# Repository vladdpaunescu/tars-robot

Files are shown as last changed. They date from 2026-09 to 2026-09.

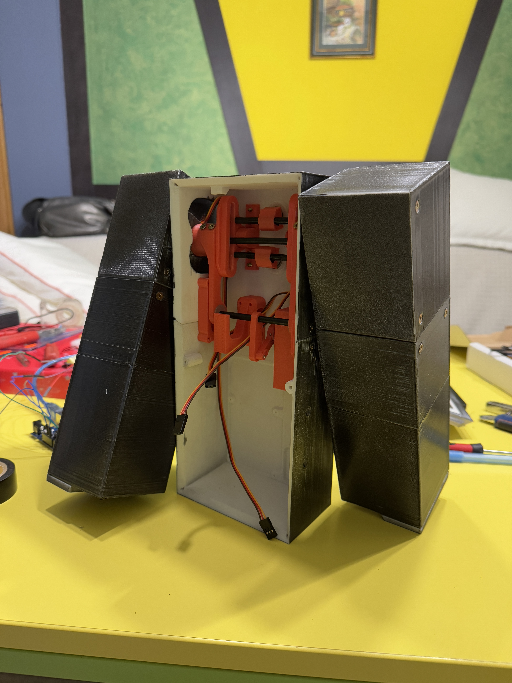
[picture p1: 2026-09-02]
docs/photos/IMG_1189.JPG

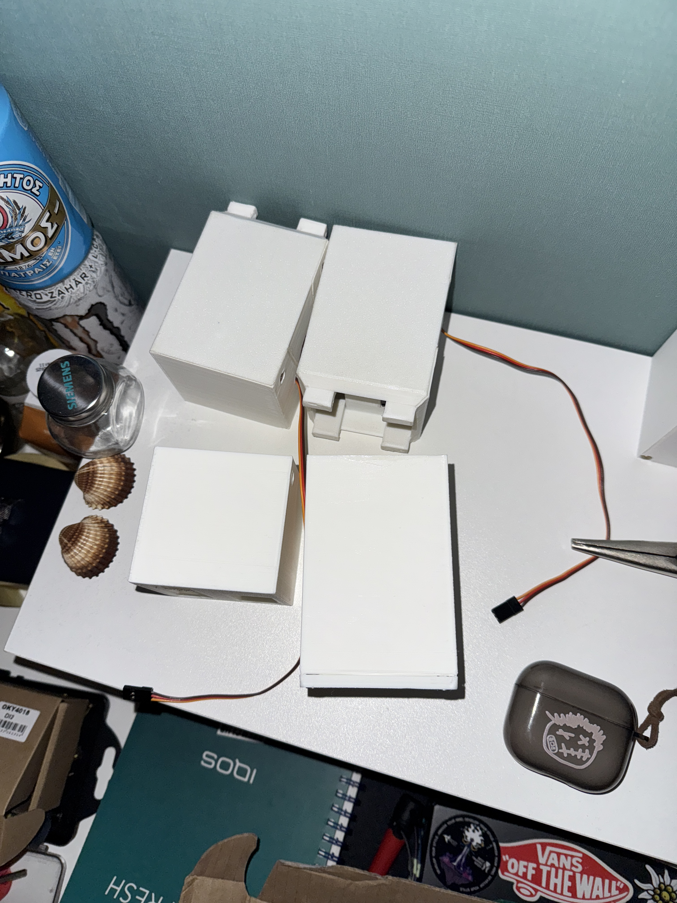
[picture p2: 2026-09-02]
docs/photos/IMG_1141.JPG

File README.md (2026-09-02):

# TARS Robot

As part of the Robotics course, I developed a robot inspired by the character TARS from the movie *Interstellar*. This project was a challenge, requiring the integration of knowledge in mechanics, electronics, and computer science.

## Overview

TARS is a walking robot that replicates the rectangular monolith locomotion of its cinematic counterpart. It pivots and steps forward by coordinating three servo motors through a Raspberry Pi, controlled in real time via an Xbox gamepad.

## Hardware

| Component | Role |
| --- | ---- |
| Raspberry Pi | Main compute unit, runs all Python code |
| PCA9685 PWM driver | Controls up to 16 servos over I2C (address `0x40`) |
| Servo — Center Lift (ch 0) | Raises and lowers the torso vertically |
| Servo — Port Drive (ch 1) | Rotates the torso to the port (left) side |
| Servo — Starboard Drive (ch 2) | Rotates the torso to the starboard (right) side |
| Xbox controller | Wireless gamepad input via `evdev` |

## Mechanics

All structural parts were designed in Fusion 360 (`cad/tars_redefined_2 v5.f3d`) and 3D-printed.

### Body

- Upper and lower chassis, upper/lower lids
- Suspension assembly: main leg mounts, suspension mounts (left/right), spring drivers, upper structure mounts, servo wheel mounts, vertical servo clips, screen support
- Axle assembly: main axle and secondary axles

### Feet

- Arms, hulls, foot pads, lids, servo clips

## Software Architecture

```text
TARS_Runner.py            ← entry point; reads Xbox controller events
    └── TARS_Servo_Abstractor3.py  ← high-level motion commands
            └── TARS_Servo_Controller3.py  ← low-level PWM sequences
```

### TARS_Runner.py

Reads gamepad events via `evdev` and dispatches motion commands:

| Input | Action |
| ----- | --- |
| D-Pad Up | Step forward |
| D-Pad Left | Turn left |
| D-Pad Right | Turn right |
| D-Pad Down | Toggle pose / unpose |
| Button X + mode | Star main motion (plus/minus direction) |
| Button `+` / `-` | Toggle direction mode |

### TARS_Servo_Abstractor3.py

High-level gait primitives built from controller sequences:

- `stepForward()` — lift → lean forward → bump → return
- `turnLeft()` / `turnRight()` — lower → pivot → return to neutral
- `pose()` / `unpose()` — lean backward into display pose and recover

### TARS_Servo_Controller3.py

Low-level servo control using `Adafruit_PCA9685`. Manages smooth PWM transitions with configurable speed (sleep intervals between increments) and supports parallel axis movement via Python threads.

### pozitie_initiala_servo.io.ino

Arduino sketch used during calibration to set all servos to their neutral positions via the PCA9685 library.

## Repository Structure

```text
tars-robot/
├── TARS_Runner.py                  # Main controller loop
├── TARS_Servo_Abstractor3.py       # High-level motion abstraction
├── TARS_Servo_Controller3.py       # Low-level PWM servo control
├── pozitie_initiala_servo.io/      # Arduino calibration sketch
├── cad/                            # Fusion 360 source + STL files
│   ├── tars_redefined_2 v5.f3d
│   ├── BODY/
│   └── FOOTS/
└── docs/                           # Documentation, schematics, and photos
    ├── Documentation.pdf
    ├── Proiect_Robo_Paunescu_Plesu.docx
    ├── RobotTars-Copiere.pptx
    ├── 525125-Schematic__50863__42807.webp
    └── photos/
```

## Dependencies

```text
evdev
Adafruit_PCA9685
smbus
```

Install on Raspberry Pi:

```bash
pip install evdev adafruit-pca9685 smbus2
```

## Running

```bash
python3 TARS_Runner.py
```

Ensure the PCA9685 is connected on I2C bus 1 and the Xbox controller is detected at `/dev/input/event8` (adjust the path in `TARS_Runner.py` if needed).

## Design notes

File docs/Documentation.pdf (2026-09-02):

### Departamentul Automatică şi Tehnologia Informaţiei

# PROIECT LA ROBOTICĂ

# Robot TARS

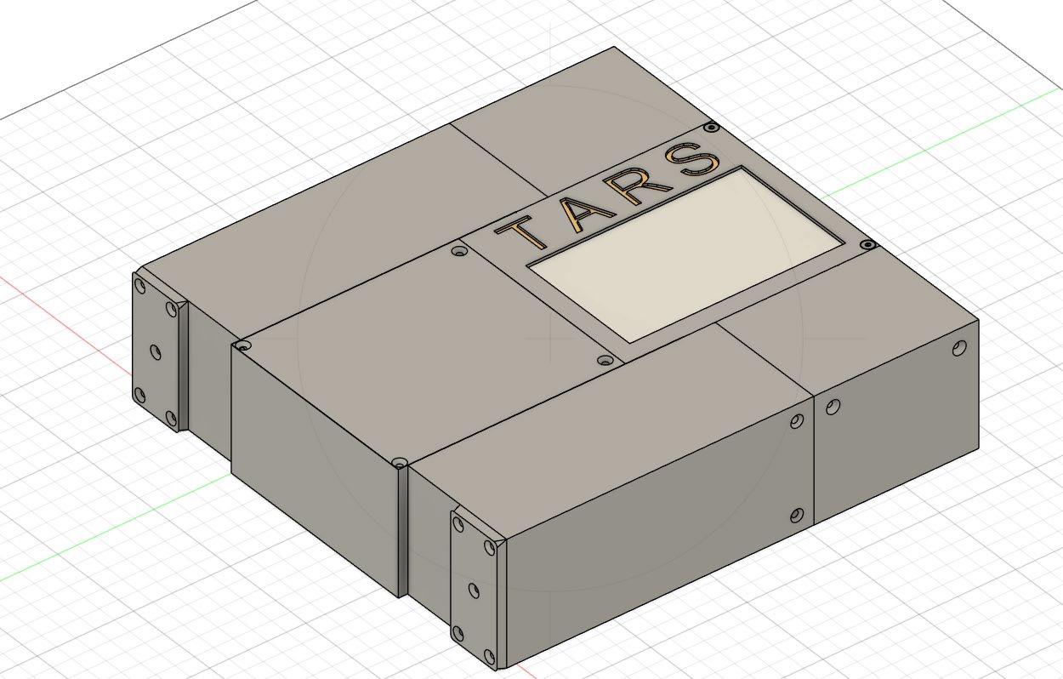
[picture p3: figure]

## Păunescu Vlad-Ioan Pleșu Robert Ștefănuț

## Gr.4LF433 - AIA - II

### BRAȘOV, 2024-2025

Departamentul Automatică şi Tehnologia Informaţiei
Programul de studii Automatică şi Informatică Aplicată - Tehnologia Informației - Robotică Proiect la PA - SDA - JAVA

## CUPRINS

Proiect la PA - SDA - JAVA

### Cap 1. DESCRIEREA SCOPULUI ȘI A FUNCȚIONALITĂȚII ROBOTULUI

Robotul TARS este un asistent robotic inovator, proiectat să combine utilitatea practicului cu o prezență socială agreabilă. Conceput pentru a sprijini utilizatorii în activitățile lor zilnice, TARS aduce un echilibru perfect între funcționalitate și design simplificat.

### 1.1 Caracteristici inovatoare

Deși la prima vedere TARS poate părea un robot minimalist, cu o structură bazată pe două picioare, fiecare echipat cu o singură articulație, complexitatea sa inginerescă stă într-un mecanism avansat de mobilitate. Pentru a depăși limitările inițiale, echipa de dezvoltare a proiectat un sistem de suspensie unic, imprimat 3D, care a transformat mobilitatea robotului în mod semnificativ.

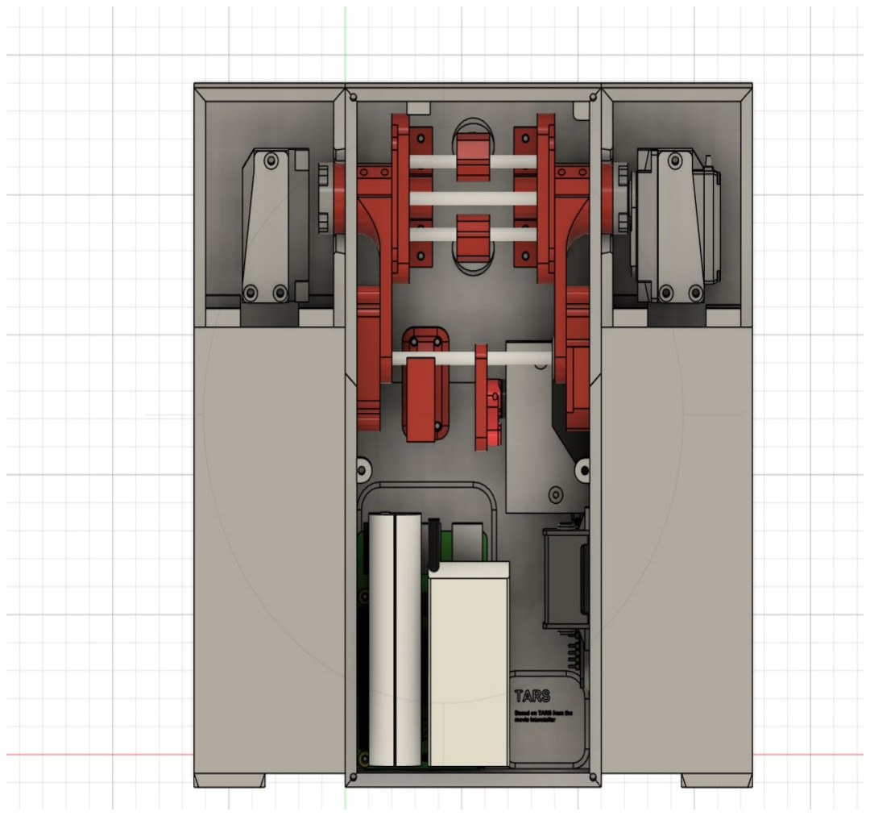
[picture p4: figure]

Figura 1 - Asamblu interior

Proiect la PA - SDA - JAVA

### 1.2 Provocări și soluții

La primele teste, robotul s-a confruntat cu restricții în mișcare, cauzate de lipsa unui mecanism de flexibilitate între picioare și trunchiul central. Soluția a constat într-un sistem de suspensie integrat, care permite transferul mișcării printr-o punte centrală ridicată, acționată de motoare de mare precizie. Această punte nu doar că permite mișcări naturale ale brațelor, dar oferă și stabilitate crescută pe durata mersului.

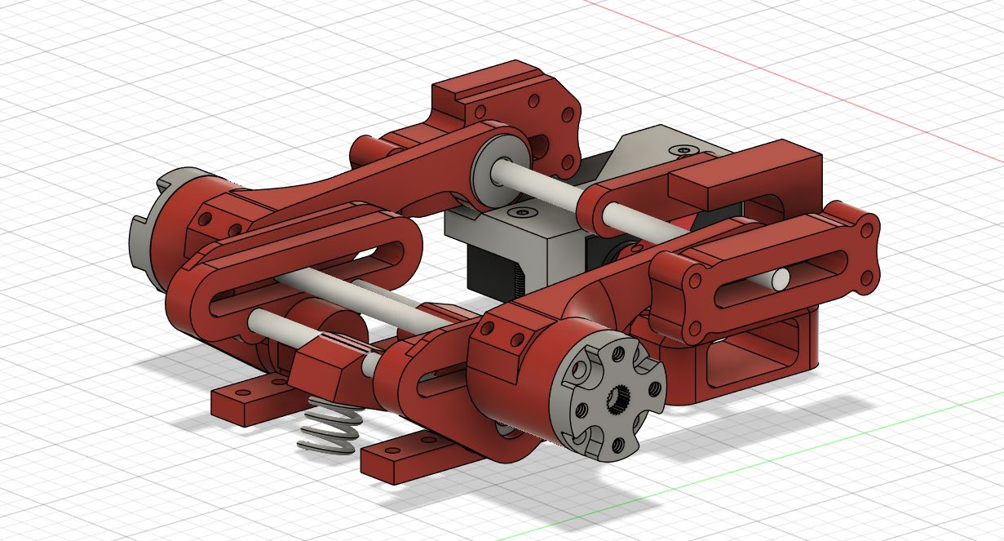
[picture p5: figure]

Figura 2 - Sistem de suspensie

Pe partea de software, au apărut dificultăți legate de afișarea pe ecran și de conceperea unui cod pentru apelarea unui sistem de inteligență artificială. Deoarece nu am găsit o soluție AI gratuită potrivită, am analizat alternative și am decis să folosim un controller de Xbox One pentru a controla mișcările robotului. Această abordare a oferit o soluție practică, facilitând controlul robotului în timp ce explorăm opțiuni AI pe termen lung.

Proiect la PA - SDA - JAVA

### 1.3 Rezultate

Datorită acestor ajustări, TARS a trecut de la un prototip funcțional, dar instabil, la un model robust și fiabil. Acum, robotul este capabil să execute mișcări continue timp de ore într-un mod natural, replicând fidel mișcările inspirate din celebra producție cinematografică.
Am reușit să conectăm ecranul robotului, afișând deocamdată doar linii de cod. Totodată, robotul răspunde prompt la comenzile transmise prin controllerul de Xbox One, asigurând o interacțiune eficientă și fluidă cu utilizatorul.

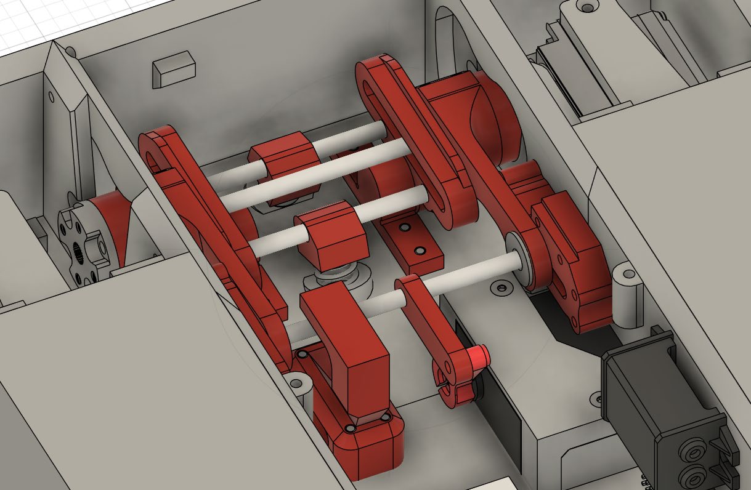
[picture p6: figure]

Figura 3 - Sistemul de suspensie in configuratia robotului

Proiect la PA - SDA - JAVA

### Cap. 2. ARHITECTURA

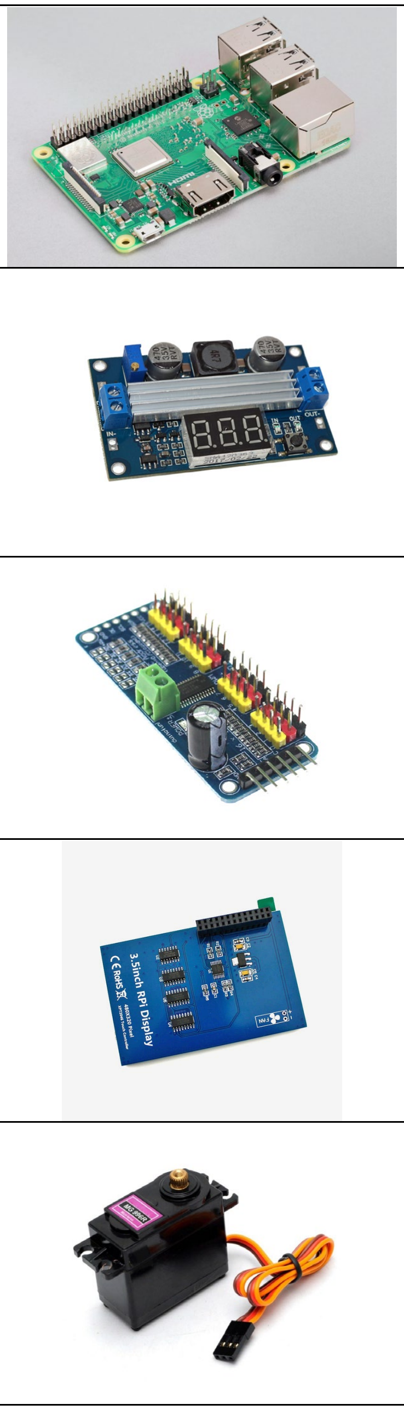
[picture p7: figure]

Raspberry Pi Model 3B+ (https://www.hackster.io/raspberry-pi/products/raspberry-pi-3-model-b?ref=project-224833)

DC Convertor de Joasa Tensiune 12V-6V

16-Channel 12-bit PWM/Servo Driver I2C interface PCA9685

3.5" RPI Display XPT2046

3x MG996R Servo motor

Proiect la PA - SDA - JAVA

### Cap. 3 CODUL FOLOSIT

### 3.1. Servo Abstractor:

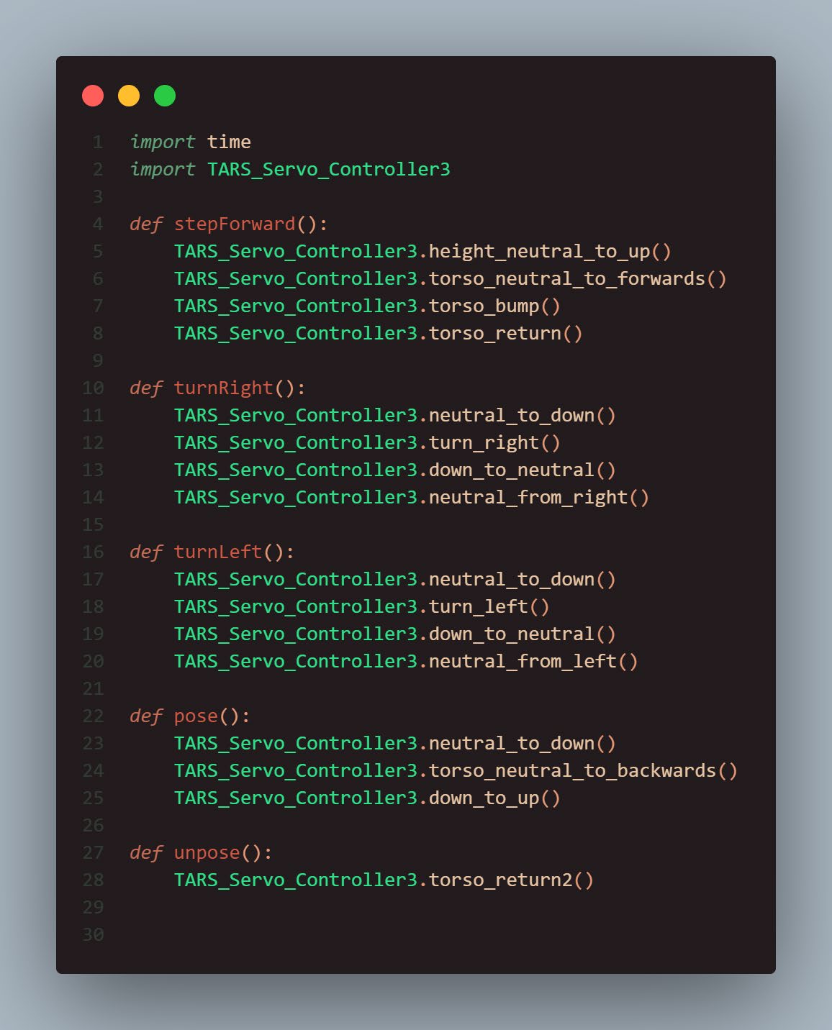
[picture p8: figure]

Proiect la PA - SDA - JAVA

### 3.2 TARS Runner

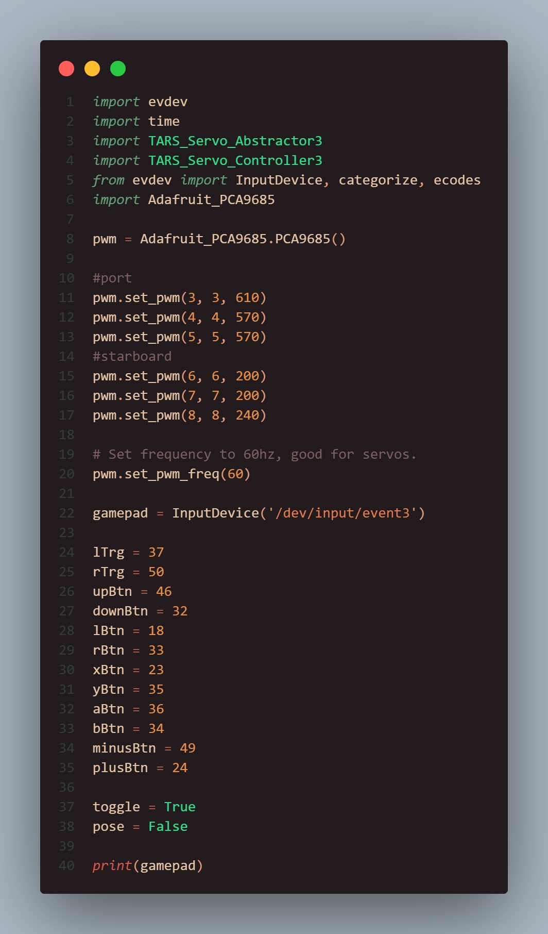
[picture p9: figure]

Proiect la PA - SDA - JAVA

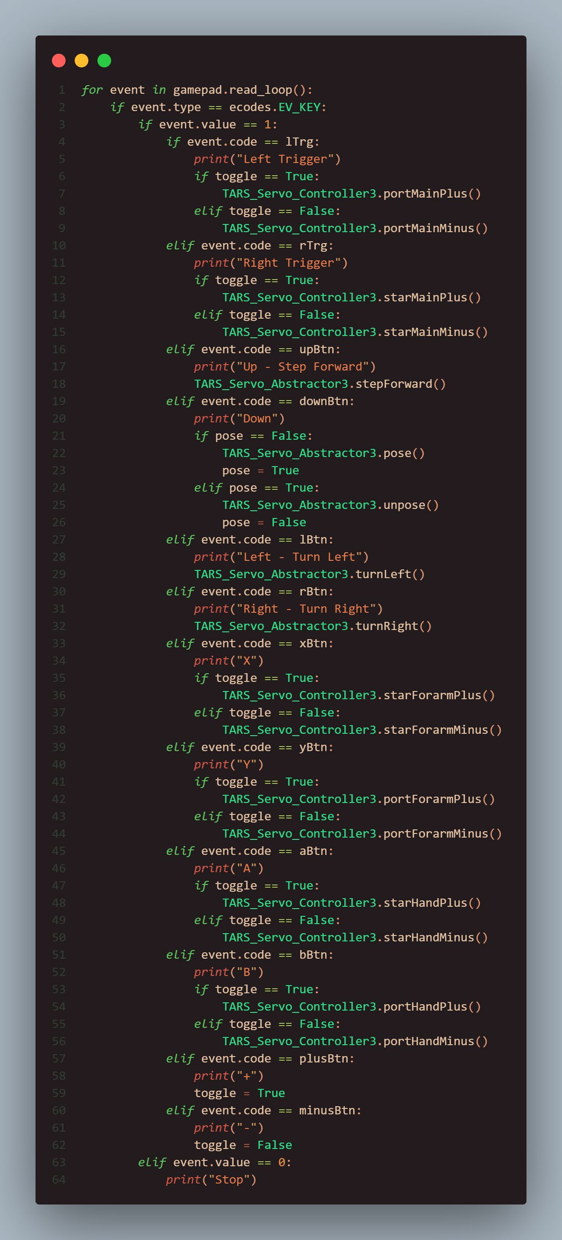
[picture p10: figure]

Proiect la PA - SDA - JAVA

### 3.3. Servo Controller

Proiect la PA - SDA - JAVA

Proiect la PA - SDA - JAVA

### Cap. 4. PLANURI DE VIITOR

Un obiectiv esențial în dezvoltarea viitoare a robotului TARS este integrarea comenzilor vocale, susținută de tehnologii avansate de inteligență artificială. Această funcționalitate va permite utilizatorilor să comunice direct cu robotul, care va interpreta și executa comenzi în timp real, devenind astfel un asistent interactiv și personalizat.
Totodată, securitatea și confidențialitatea datelor sunt priorități majore. Pentru a proteja informațiile utilizatorilor, TARS va procesa local toate interacțiunile, evitând transmiterea datelor către servere externe și respectând normele GDPR. În plus, vor fi implementate funcții pentru gestionarea și ștergerea datelor, oferind utilizatorilor control deplin asupra informațiilor personale.
Progresul proiectului va fi susținut prin colaborări strategice cu organizații de cercetare, universități și companii din domeniul roboticii și AI. Aceste parteneriate vor facilita integrarea unor tehnologii de ultimă generație și testarea robotului în diverse medii controlate, pentru a asigura performanțe optime.

### Cap. 5. VIITORUL ROBOTULUI TARS

Pe lângă integrarea comenzilor vocale și a inteligenței artificiale, TARS are un potențial vast de extindere, vizând multiple direcții de dezvoltare:
- Design modular: Robotul va fi îmbunătățit atât estetic, cât și funcțional, prin adoptarea unui design modular, ce va permite instalarea facilă a noilor componente.
- Autonomie sporită: Integrarea unor tehnologii avansate de învățare automată îi va permite robotului să opereze independent și să se adapteze la schimbările din mediul înconjurător.
- Integrare smart home: TARS va putea comunica cu dispozitive inteligente din locuință, precum sisteme de iluminat, termostate sau electrocasnice, oferind o experiență completă de automatizare.
- Siguranța locuinței: Integrarea cu sisteme de securitate va permite monitorizarea casei și notificarea utilizatorilor sau autorităților în cazul unor situații de urgență.
- Interacțiune socială: TARS va deveni un companion social, sprijinind utilizatorii care se confruntă cu izolarea și oferind activități recreative și conversație.

Proiect la PA - SDA - JAVA

### Cap. 6. CONCLUZII

Robotul TARS reprezintă un pas important în evoluția asistenților robotizați destinați să sprijine utilizatorii în diverse activități cotidiene. Cu un design simplu, dar eficient, TARS oferă deja un prototip solid care poate fi îmbunătățit prin integrarea de noi tehnologii, precum comenzi vocale și AI. În viitor, TARS va deveni nu doar un instrument de asistență, ci și un companion de încredere, capabil să răspundă nevoilor diverse ale utilizatorilor și să adreseze problemele sociale și de accesibilitate.

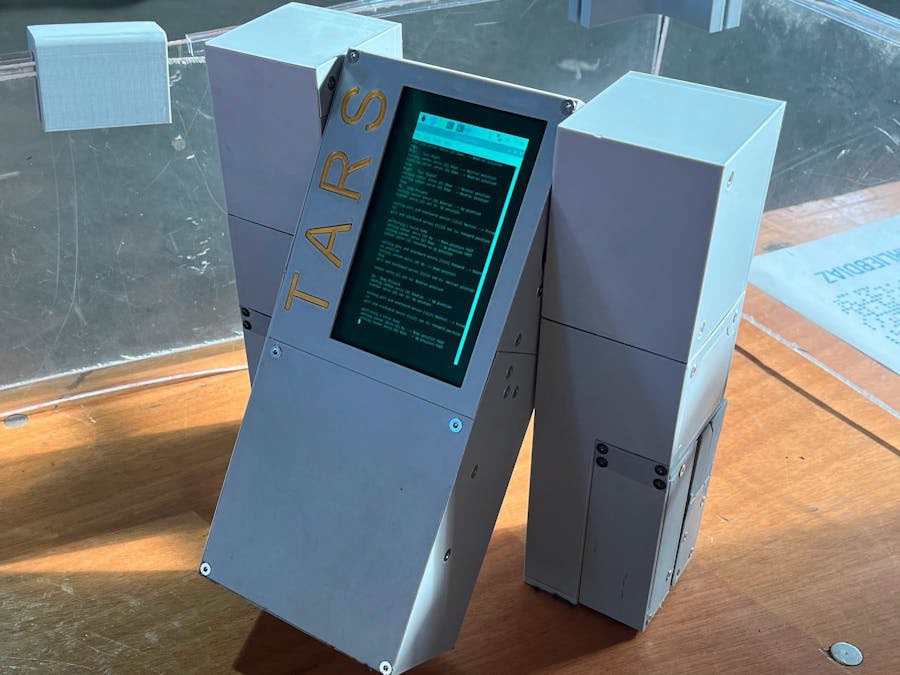
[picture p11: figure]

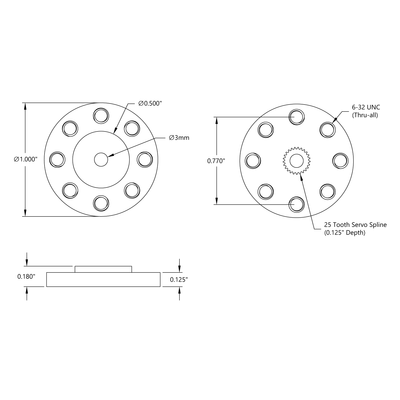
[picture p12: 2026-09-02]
docs/525125-Schematic__50863__42807.webp

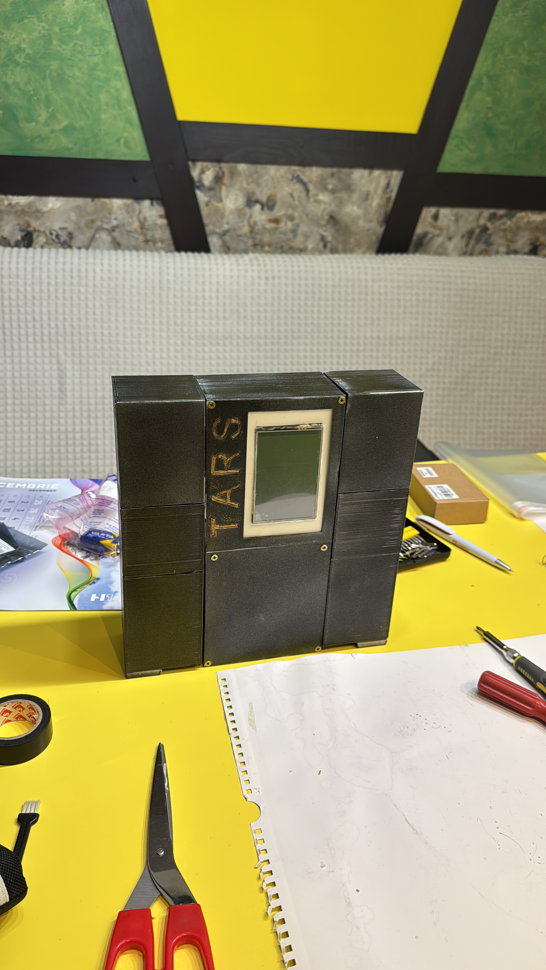
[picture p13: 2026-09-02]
docs/photos/4BB93263-8DDB-4133-9F45-90A4803A2489.jpg

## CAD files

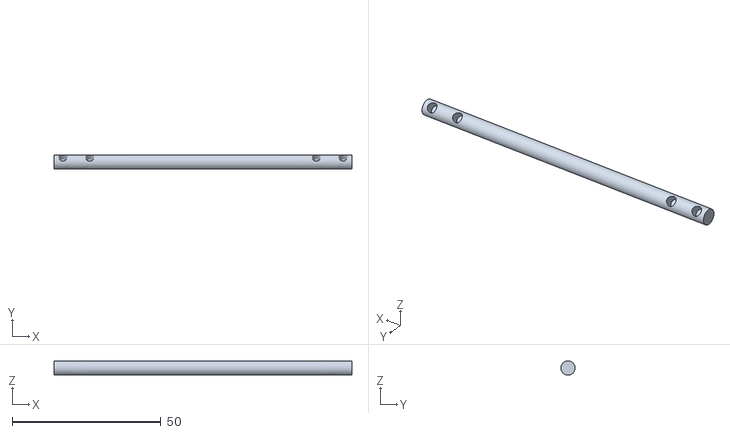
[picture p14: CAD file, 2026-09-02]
cad/BODY/axle/mainAxle - 1buc.stl
100.0 x 4.80 x 4.79

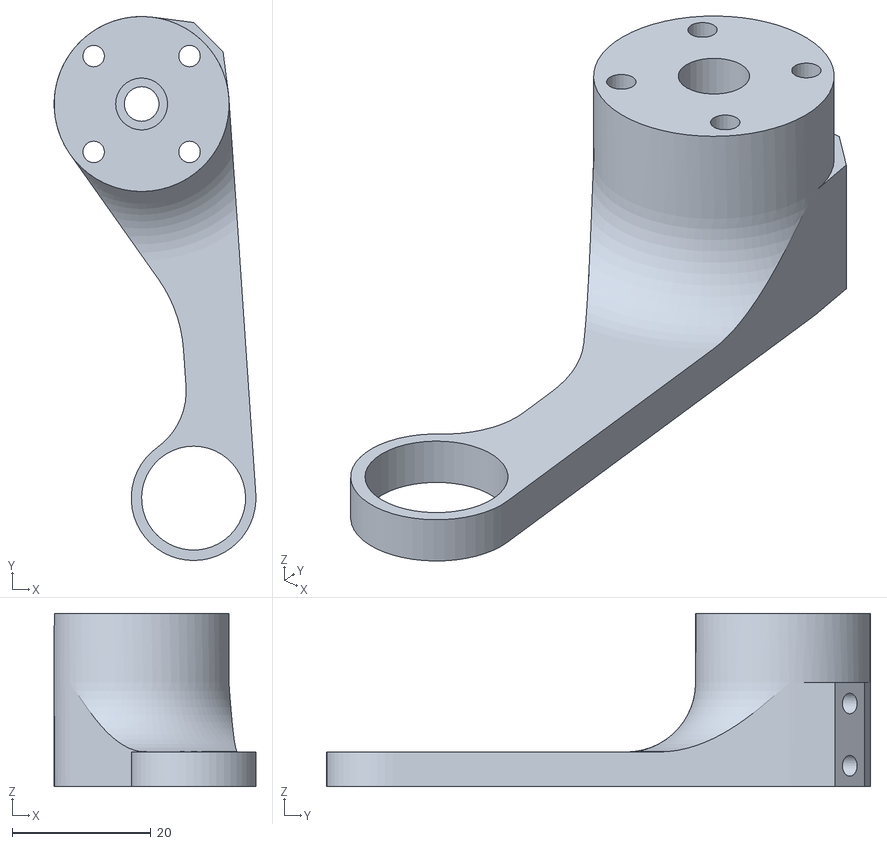
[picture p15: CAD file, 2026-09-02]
cad/BODY/suspension/mainLegMount - 2buc.stl
29.1 x 78.5 x 25.0

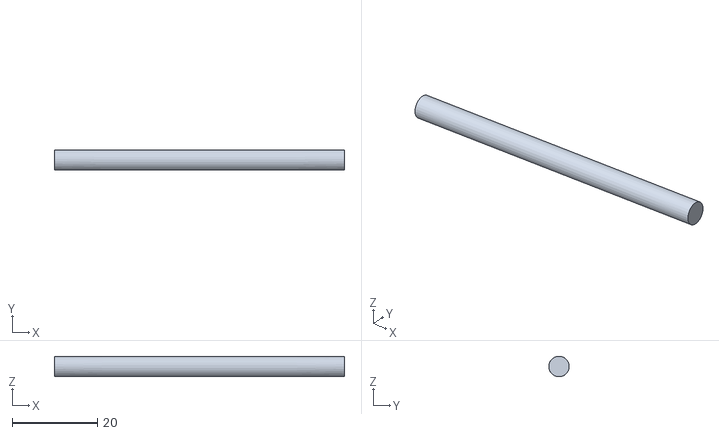
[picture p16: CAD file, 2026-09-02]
cad/BODY/axle/secondaryAxle - 2buc.stl
68.0 x 4.80 x 4.79

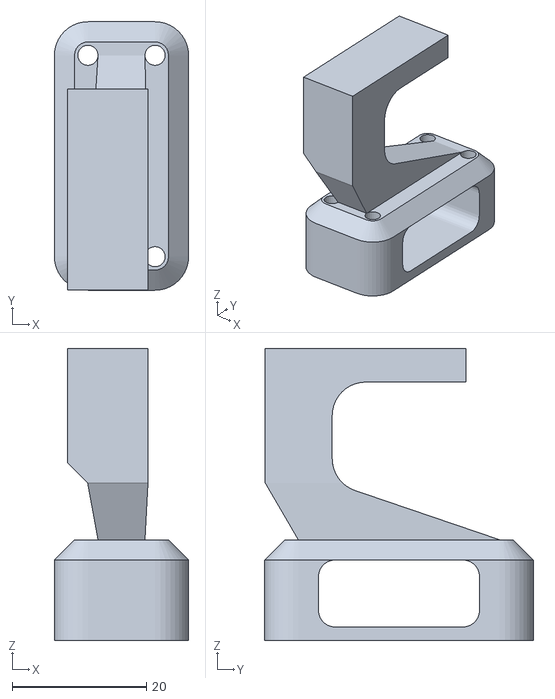
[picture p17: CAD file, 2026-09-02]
cad/BODY/suspension/screenSupport - 1buc.stl
20.0 x 40.0 x 43.5

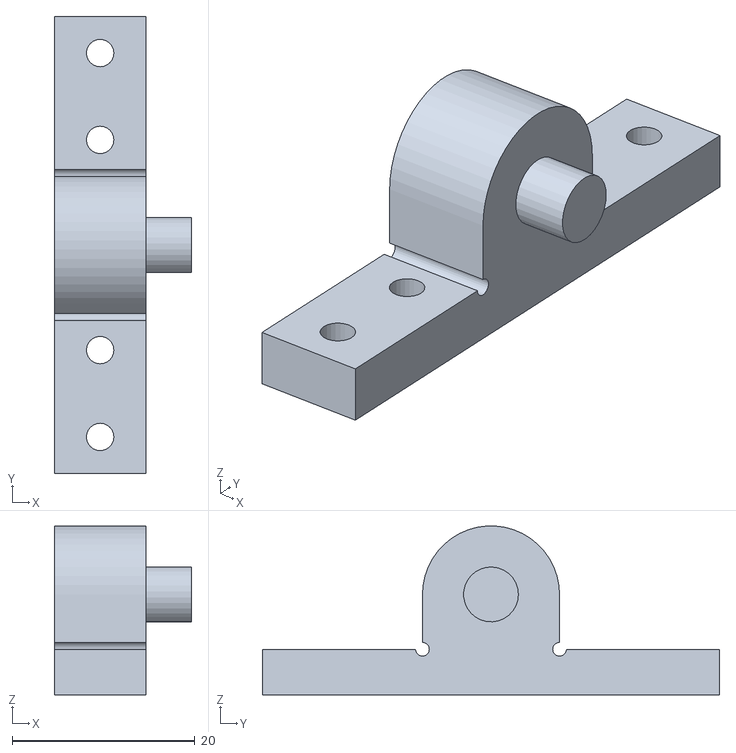
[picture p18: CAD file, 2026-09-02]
cad/BODY/upperChassis/suspensionMount - 2buc.stl
15.0 x 50.0 x 18.5

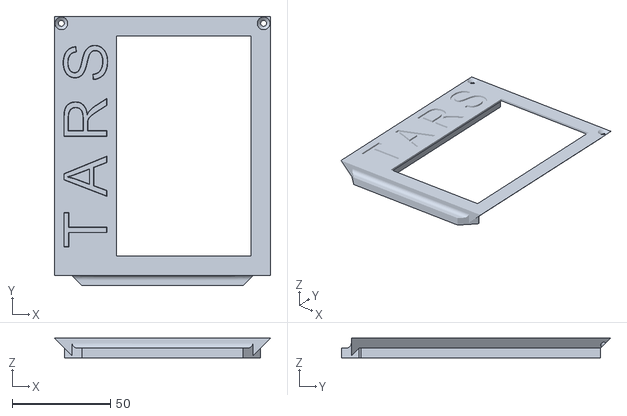
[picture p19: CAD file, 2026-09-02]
cad/BODY/upperLid - 1buc.stl
110.0 x 137.0 x 10.00

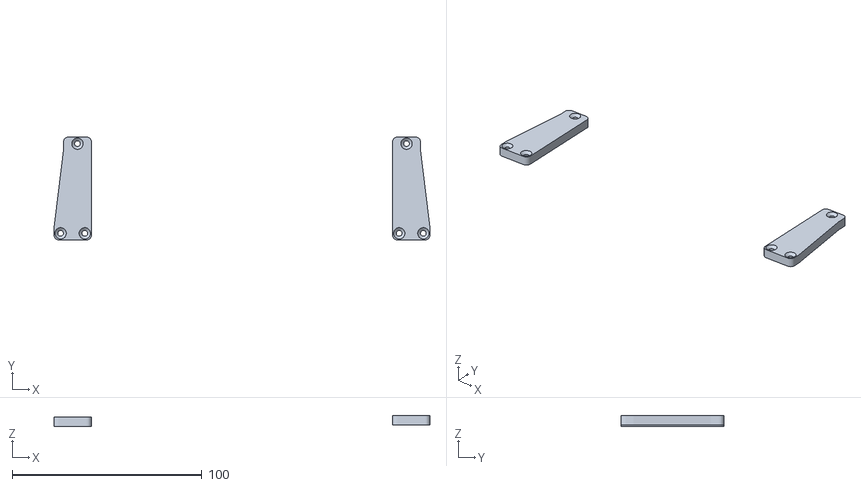
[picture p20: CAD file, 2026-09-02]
cad/FOOTS/servoClips.stl
198.4 x 54.3 x 6.00

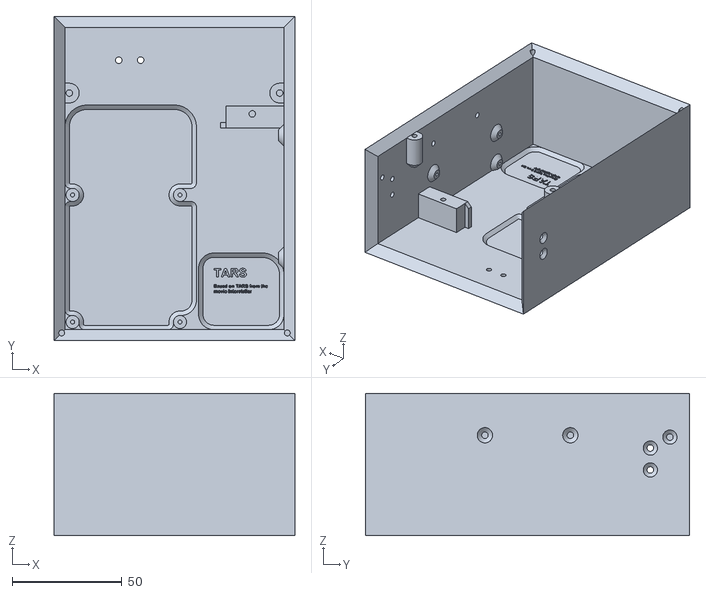
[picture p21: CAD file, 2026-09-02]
cad/BODY/lowerChassisCase.stl
110.0 x 148.0 x 65.0

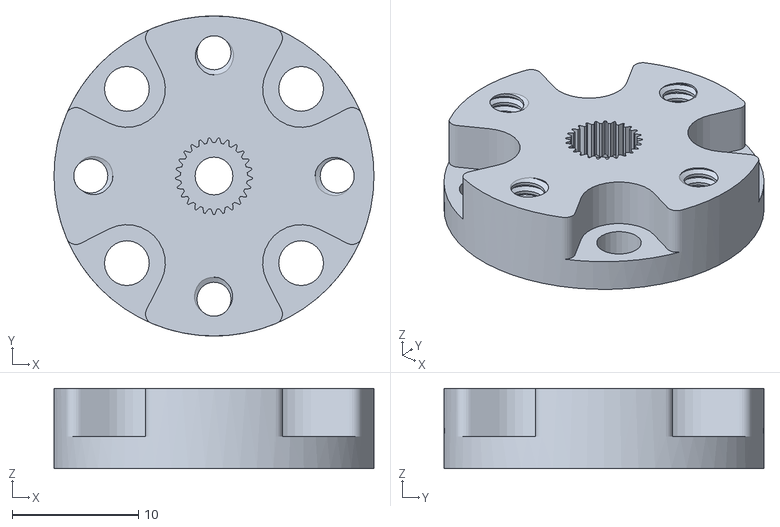
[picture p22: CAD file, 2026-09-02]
cad/BODY/suspension/roataServo - 2buc.stl
25.4 x 25.4 x 6.35

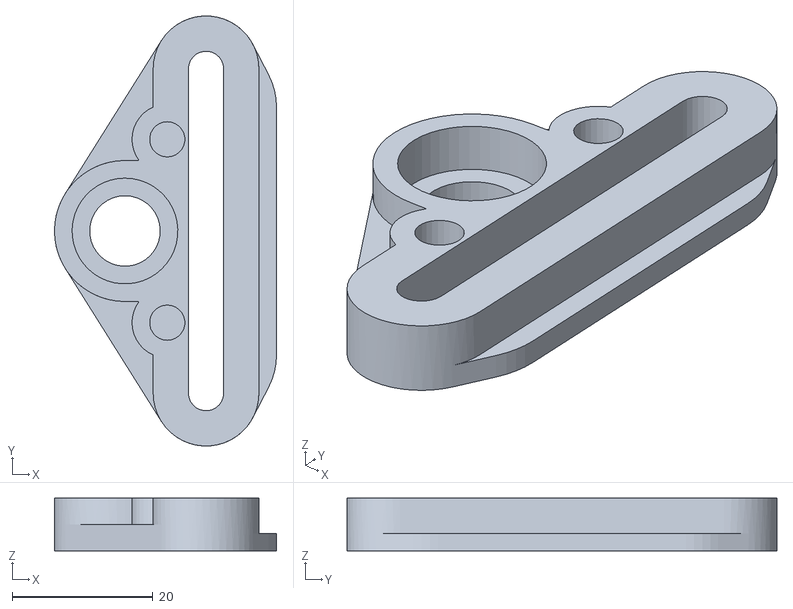
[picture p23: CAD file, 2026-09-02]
cad/BODY/upperChassis/springDriver - 2buc.stl
31.5 x 61.0 x 7.50

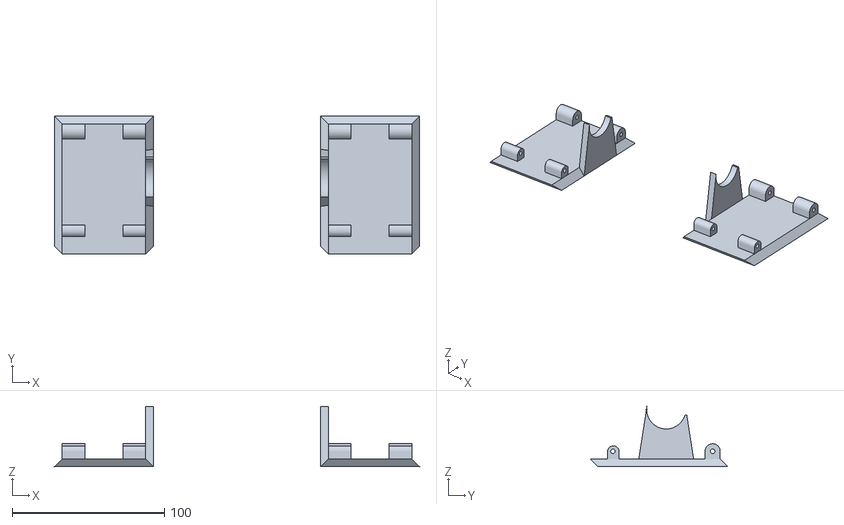
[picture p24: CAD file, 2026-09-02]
cad/FOOTS/lids.stl
240.0 x 90.5 x 39.5

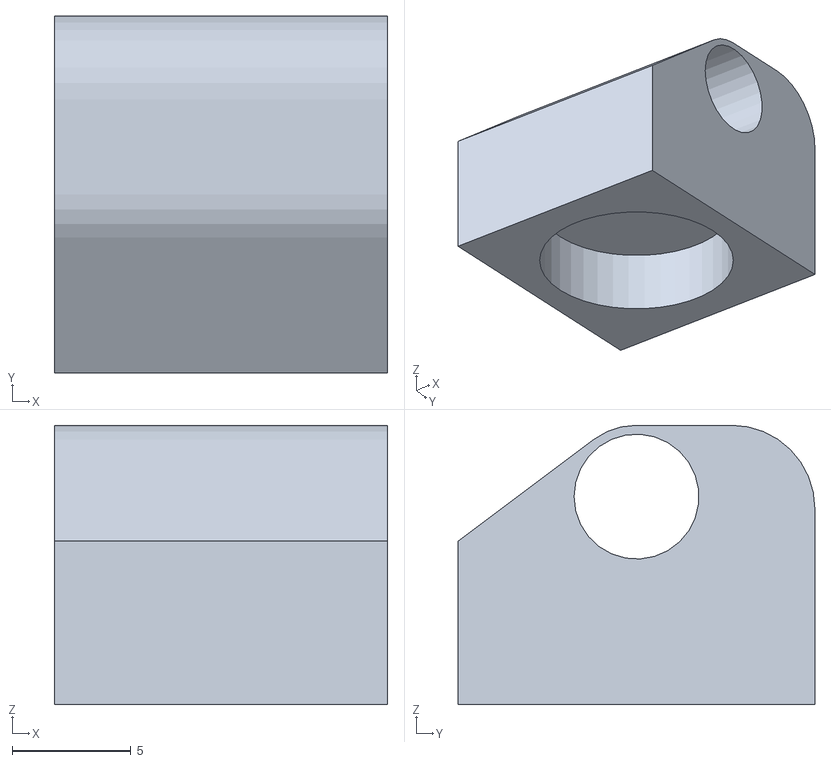
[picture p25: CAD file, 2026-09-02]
cad/BODY/suspension/upperStructMount - 2buc.stl
14.0 x 15.0 x 11.7

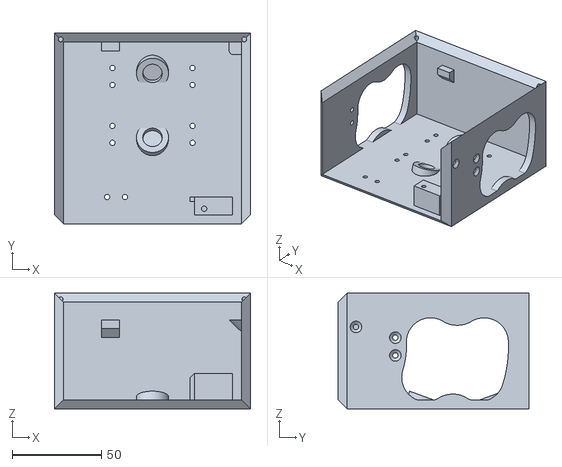
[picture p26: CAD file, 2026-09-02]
cad/BODY/upperChassisBody - 1buc.stl
110.0 x 107.0 x 65.0

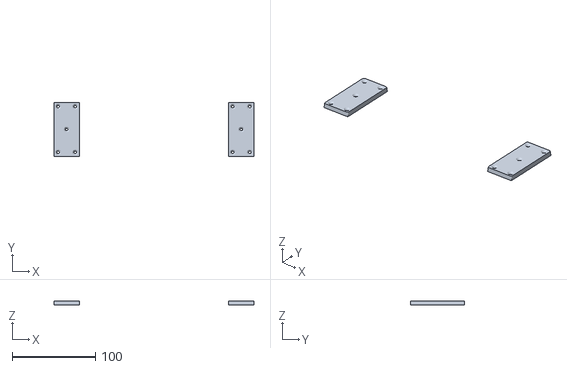
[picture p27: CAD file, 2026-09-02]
cad/FOOTS/footPads.stl
240.0 x 65.0 x 5.00

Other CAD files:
cad/BODY/lowerLid - 1buc.stl
cad/FOOTS/armsBoth.stl
cad/BODY/suspension/verticalServoClip - 1buc.stl
cad/FOOTS/hulls.stl
cad/BODY/suspension/spacer - 1buc.stl
cad/BODY/suspension/suspensionMountRight - 1buc.stl
cad/BODY/suspension/suspensionMountleft - 1buc.stl
cad/tars_redefined_2 v5.f3d

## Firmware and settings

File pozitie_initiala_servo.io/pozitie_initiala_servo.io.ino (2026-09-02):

#include <Wire.h>
#include <Adafruit_PWMServoDriver.h>

// Inițializează driverul PCA9685
Adafruit_PWMServoDriver pwm = Adafruit_PWMServoDriver();

void setup() {
  Serial.begin(9600);
  Serial.println("Pornire PCA9685");
  
  pwm.begin();
  pwm.setPWMFreq(60); // Setare frecvență PWM pentru servouri (50Hz)
}

void loop() {

  int neutralHeight = 465, neutralPort = 276, neutralStarboard = 340;

  pwm.setPWM(1, 0, neutralHeight);
  delay(1000);

  // pwm.setPWM(2, 1, neutralPort);
  // delay(1000);

  // pwm.setPWM(3, 2, neutralStarboard);
  // delay(1000);
}

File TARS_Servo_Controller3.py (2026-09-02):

from __future__ import division
import time
import Adafruit_PCA9685
from threading import Thread
import smbus

# Specificează manual bus-ul I2C (de obicei 1 pe Raspberry Pi)
bus = smbus.SMBus(1)

pwm = Adafruit_PCA9685.PCA9685(address=0x40, busnum=1)

# Set frequency to 60hz, good for servos.
pwm.set_pwm_freq(60)

# Center Lift Servo (0) Values
upHeight = 255
neutralHeight = 345
downHeight = 435

# Port Drive Servo (1) Values
forwardPort = 420
neutralPort = 343
backPort = 266

# Starboard Drive Servo (2) Values
forwardStarboard = 330
neutralStarboard = 407
backStarboard = 484

# moves the torso from a neutral position upwards, allowing the torso to pivot forwards or backwards
def height_neutral_to_up():
	height = neutralHeight
	print('setting center servo (0) Neutral --> Up position')
	while (height > upHeight):
		height = height - 1
		pwm.set_pwm(0, 0, height)
		time.sleep(0.001)
	print('center servo (0) set to: Up position\n ')

# rotates the torso outwards, enough so that when TARS pivots and lands, the bottom of the torso is 
# flush with the ground. Making the torso flush with the ground is an intentional improvement from
# previous programs, where TARS would land and then slide a little on smooth surfaces, which while
# allowing for a simple walking program, inhibited TARS' ability to walk on surfaces with different 
# coefficients of friction
def torso_neutral_to_forwards():
	port = neutralPort
	starboard = neutralStarboard
	print('setting port and starboard servos (1)(2) Neutral --> Forward')
	while (port < forwardPort):
		port = port + 1
		starboard = starboard - 1
		pwm.set_pwm(1, 1, port)
		pwm.set_pwm(2, 2, starboard)
		time.sleep(0.0001)
	print('port and starboard servos (1)(2) set to: Forward position\n ')

def torso_neutral_to_backwards():
	port = neutralPort
	starboard = neutralStarboard
	print('setting port and starboard servos (1)(2) Neutral --> Forward')
	while (port > backPort):
		port = port - 1
		starboard = starboard + 1
		pwm.set_pwm(1, 1, port)
		pwm.set_pwm(2, 2, starboard)
		time.sleep(0.0001)
	print('port and starboard servos (1)(2) set to: Forward position\n ')

# rapidly shifts the torso height from UP --> DOWN and then returns --> UP, which should cause TARS 
# to pivot and land on it's torso
def torso_bump():
	height = upHeight
	print('performing a torso bump\nsetting center servo (0) Up --> Down position FAST')
	while (height < downHeight):
		height = height + 2
		pwm.set_pwm(0, 0, height)
		time.sleep(0.000001)
	print('setting center servo (0) Down --> Up position FAST')
	while (height > upHeight):
		height = height - 1
		pwm.set_pwm(0, 0, height)
		time.sleep(0.0001)
	print('center servo (0) returned to Up position\n')
	
# returns the torso's vertical height and rotation to centered values from up height and forward 
# rotation. Activates two external functions so movement in both axes can occur in parallel.
def torso_return():
	t1 = Thread(target = torso_return_rotation)
	t2 = Thread(target = torso_return_vertical)
	
	t1.start()
	t2.start()

# returns torso's rotation to neutral from forward
def torso_return_rotation():
	port = forwardPort
	starboard = forwardStarboard
	print('setting port and starboard servos (1)(2) Forward --> Neutral position')
	while (port > neutralPort):
		port = port - 1
		starboard = starboard + 1
		pwm.set_pwm(1, 1, port)
		pwm.set_pwm(2, 2, starboard)
		time.sleep(0.005)
	print('port and starboard servos (1)(2) set to: Neutral position\n ')

# returns torso's vertical to neutral from up	
def torso_return_vertical():
	height = upHeight
	print('setting center servo (0) Up --> Down position')
	# moving the torso down to create clearance for the rotation of the legs
	while (height < downHeight):
		height = height + 1
		pwm.set_pwm(0, 0, height)
		time.sleep(0.00005)
	# moving the torso up from down to neutral
	#time.sleep(.2)
	while (height > neutralHeight):
		height = height - 1
		pwm.set_pwm(0, 0, height)
		time.sleep(0.00001)
	print('center servo (0) set to: Neutral position\n ')

def torso_return2():
	t1 = Thread(target = torso_return_rotation2)
	t2 = Thread(target = torso_return_vertical2)
	
	t1.start()
	t2.start()

# returns torso's rotation to neutral from forward
def torso_return_rotation2():
	port = backPort
	starboard = backStarboard
	print('setting port and starboard servos (1)(2) Forward --> Neutral position')
	while (port < neutralPort):
		port = port + 1
		starboard = starboard - 1
		pwm.set_pwm(1, 1, port)
		pwm.set_pwm(2, 2, starboard)
		time.sleep(0.01)
	print('port and starboard servos (1)(2) set to: Neutral position\n ')

# returns torso's vertical to neutral from up	
def torso_return_vertical2():
	height = upHeight
	print('setting center servo (0) Up --> Down position')
	# moving the torso down to create clearance for the rotation of the legs
	while (height < downHeight):
		height = height + 1
		pwm.set_pwm(0, 0, height)
		time.sleep(0.001)
	# moving the torso up from down to neutral
	time.sleep(.25)
	while (height > neutralHeight):
		height = height - 1
		pwm.set_pwm(0, 0, height)
		time.sleep(0.001)
	print('center servo (0) set to: Neutral position\n ')


# moves the torso from neutral position to down
def neutral_to_down():
    height = neutralHeight
    print('setting center servo (0) Neutral --> Down position')
    while (height < downHeight):
        height = height + 1
        pwm.set_pwm(0, 0, height)
        time.sleep(0.001)
        
def down_to_up():
    height = downHeight
    print('setting center servo (0) Down --> Neutral position')
    while (height > upHeight):
        height = height - 1
        pwm.set_pwm(0, 0, height)
        time.sleep(0.001)

def down_to_neutral():
    height = downHeight
    print('setting center servo (0) Down --> Neutral position')
    while (height > neutralHeight):
        height = height - 1
        pwm.set_pwm(0, 0, height)
        time.sleep(0.001)

def neutral_to_down():
    height = neutralHeight
    print('setting center servo (0) Down --> Neutral position')
    while (height < downHeight):
        height = height + 1
        pwm.set_pwm(0, 0, height)
        time.sleep(0.001)


def turn_right():
    port = neutralPort
    starboard = neutralStarboard
    while (port < forwardPort):
        port = port + 1
        starboard = starboard + 1
        pwm.set_pwm(1, 1, port)
        pwm.set_pwm(2, 2, starboard)
        time.sleep(0.001)
        
def turn_left():
    port = neutralPort
    starboard = neutralStarboard
    while (port > backPort):
        port = port - 1
        starboard = starboard - 1
        pwm.set_pwm(1, 1, port)
        pwm.set_pwm(2, 2, starboard)
        time.sleep(0.001)
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
